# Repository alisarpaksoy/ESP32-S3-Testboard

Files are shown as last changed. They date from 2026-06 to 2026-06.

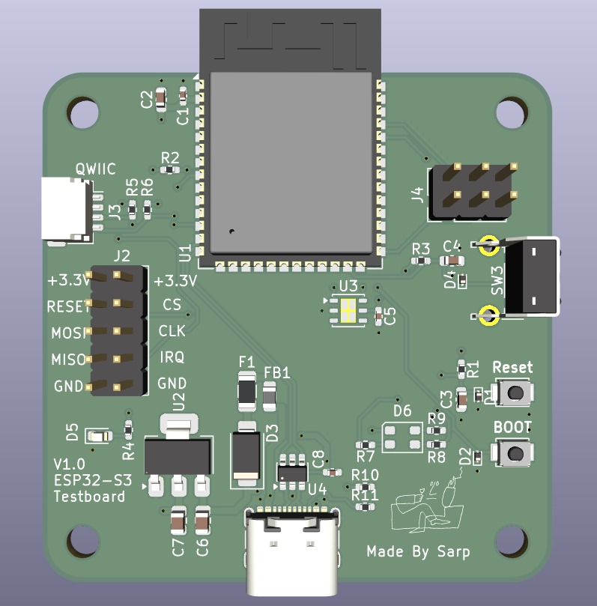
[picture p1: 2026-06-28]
Images/ESP32 S3 Layout.png

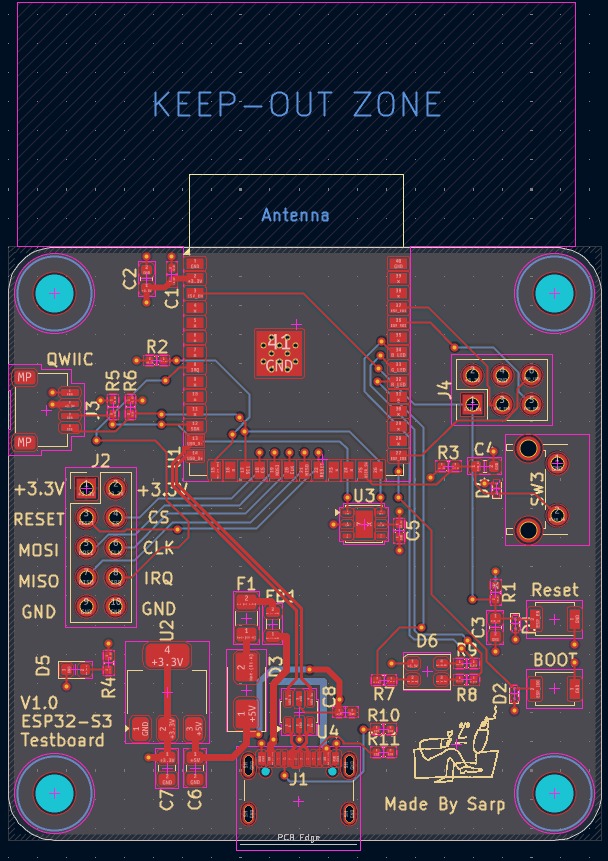
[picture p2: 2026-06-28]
Images/ESP32 S3 PCB.png

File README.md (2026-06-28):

# ESP32-S3 Testboard

## Overview

This project is a custom ESP32-S3 testboard designed in KiCad. The board was created as a compact development and testing platform for the ESP32-S3-WROOM module.

The board includes USB-C power and data connection, 3.3 V voltage regulation, boot and reset buttons, a user button, RGB LED, Qwiic I2C connector, GPIO headers, and an onboard Si7021-A20 temperature and humidity sensor.

The purpose of this project is to practice PCB design, ESP32-S3 hardware design, sensor integration, and GitHub-based engineering documentation.

## Main Features

* ESP32-S3-WROOM module
* USB-C connector for power and USB communication
* 5 V input from USB-C
* 3.3 V regulated power supply
* Boot and reset buttons
* User button
* RGB LED
* Si7021-A20 temperature and humidity sensor
* Qwiic I2C connector
* GPIO/SPI breakout headers
* ESD protection components
* Mounting holes
* ESP32-S3 antenna keepout area

## Hardware Description

### ESP32-S3 Module

The main microcontroller of the board is the ESP32-S3-WROOM module. It provides Wi-Fi, Bluetooth Low Energy, GPIO, USB, I2C, SPI, UART, PWM, ADC, and other peripheral interfaces.

The board exposes several ESP32-S3 pins through headers so the module can be used for testing and prototyping.

### Power Supply

The board is powered through the USB-C connector. The USB 5 V input is protected using a polyfuse and then regulated to 3.3 V using an LDO regulator.

The 3.3 V rail powers the ESP32-S3 module, Si7021 sensor, RGB LED, Qwiic connector, and supporting circuits.

### USB-C Interface

The USB-C connector provides power and USB data communication. The USB D+ and D− lines are connected to the ESP32-S3 USB pins for programming and serial communication.

### Boot and Reset Circuit

The board includes dedicated boot and reset buttons. The boot button is connected to GPIO0, and the reset button is connected to the ESP32-S3 enable/reset line.

These buttons allow the ESP32-S3 to be reset and placed into programming mode during firmware upload.

### Si7021 Temperature and Humidity Sensor

The board includes the Si7021-A20 digital temperature and humidity sensor. It communicates with the ESP32-S3 using the I2C bus.

This sensor can be used for:

* Temperature measurement
* Humidity measurement
* Environmental monitoring
* I2C communication testing

### Qwiic I2C Connector

A Qwiic connector is included for connecting external I2C modules. The connector provides:

* GND
* 3.3 V
* SDA
* SCL

Pull-up resistors are included on the I2C lines.

### RGB LED

The RGB LED is connected to ESP32-S3 GPIO pins through current-limiting resistors. It can be used for status indication, firmware testing, and GPIO output testing.

## Repository Structure

```text
ESP32-S3-Testboard/
│
├── README.md
├── .gitignore
│
├── kicad/
│   ├── ESP32-S3.kicad_pro
│   ├── ESP32-S3.kicad_sch
│   └── ESP32-S3.kicad_pcb
│
├── Images/
│   ├── schematic.png
│   ├── pcb_layout.png
│   └── pcb_3d_view.png
│
├── Documentation/
│   └── Datasheets/
│       ├── esp32-s3-wroom-1_wroom-1u_datasheet_en.pdf
│       └── Si7021-A20_datasheet.pdf
│
└── Manufacturing/
    ├── Gerbers/
    └── Drill/
```

## KiCad Project

The KiCad design files are located in the `kicad/` folder.

To open the project:

1. Install KiCad.
2. Open the `.kicad_pro` file.
3. Review the schematic and PCB layout.
4. Run ERC and DRC before modifying or manufacturing the board.

## Images

Project images are located in the `Images/` folder.

Included images:

* Schematic screenshot
* PCB layout screenshot
* 3D PCB render

## Manufacturing

Manufacturing files will be placed in the `Manufacturing/` folder.

Before ordering the PCB, the following checks should be completed:

* Electrical Rules Check
* Design Rules Check
* Gerber preview inspection
* Drill file verification
* USB-C footprint check
* ESP32-S3 footprint orientation check
* ESP32-S3 antenna keepout check
* Power trace width check
* I2C pull-up resistor verification

## Project Status

* [x] Schematic completed
* [x] PCB layout completed
* [x] ESP32-S3 module added
* [x] USB-C interface added
* [x] 3.3 V regulator added
* [x] Si7021 sensor added
* [x] Qwiic connector added
* [x] RGB LED added
* [ ] PCB manufactured
* [ ] Board assembled
* [ ] Power supply tested
* [ ] USB programming tested
* [ ] Si7021 sensor tested
* [ ] Example firmware added

## Author

Ali Sarp Aksoy
Mechatronics Engineering Student
Kraków, Poland

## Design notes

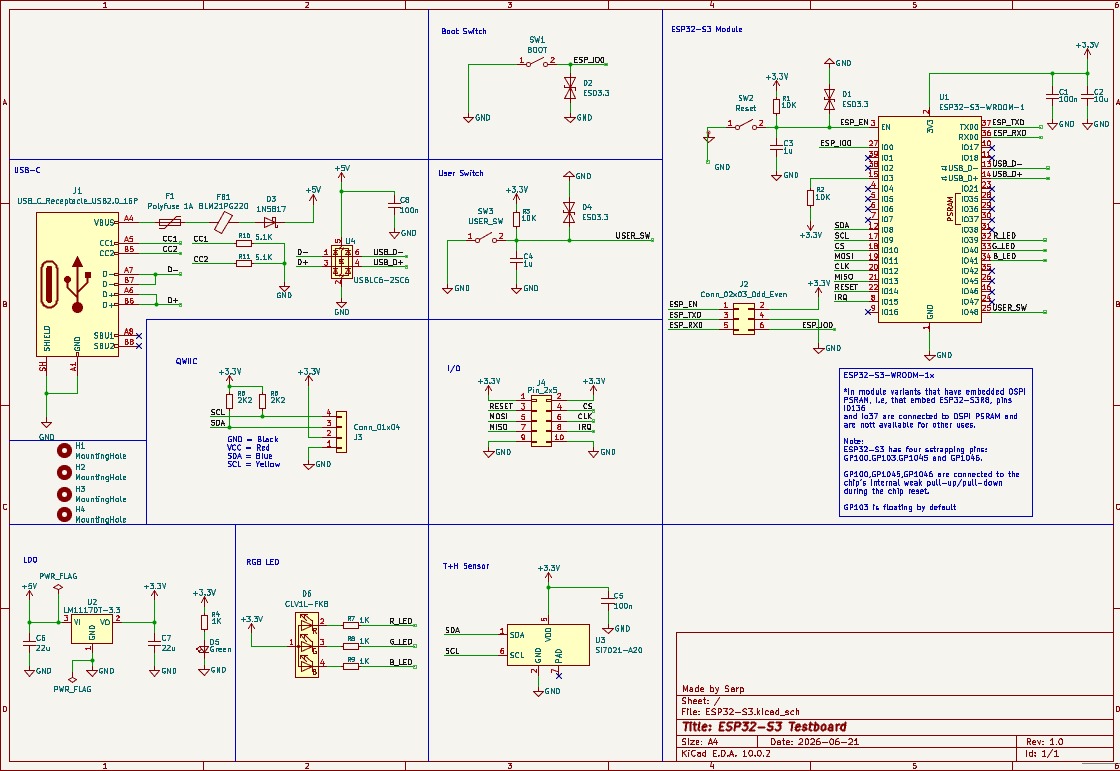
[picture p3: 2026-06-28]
Images/ESP32 S3 SCH.png

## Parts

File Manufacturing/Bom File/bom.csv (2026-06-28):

Designator | Footprint | Quantity | Value | LCSC Part #
C1, C5, C8 | 0402 | 3 | 100n
C2 | 0603 | 1 | 10u
C3, C4 | 0603 | 2 | 1u
C6, C7 | 0805 | 2 | 22u
D1, D2, D4 | D_SOD-923 | 3 | ESD3.3
D3 | D_SMA | 1 | 1N5817
D5 | 0603 | 1 | Green
D6 | LED_Cree-PLCC4_3.2x2.8mm_CCW | 1 | CLV1L-FKB
F1 | 1206 | 1 | Polyfuse 1A
FB1 | 0805 | 1 | BLM21PG220
J1 | USB_C_Receptacle_GCT_USB4105-xx-A_16P_TopMnt_Horizontal | 1 | USB_C_Receptacle_USB2.0_16P
J2 | PinHeader_2x05_P2.54mm_Vertical | 1 | Conn_02x03_Odd_Even
J3 | JST_SH_SM04B-SRSS-TB_1x04-1MP_P1.00mm_Horizontal | 1 | Conn_01x04
J4 | PinHeader_2x03_P2.54mm_Vertical | 1 | Pin_2x5
R1, R2, R3 | 0402 | 3 | 10K
R10, R11 | 0402 | 2 | 5.1K
R4, R7, R8, R9 | 0402 | 4 | 1K
R5, R6 | 0402 | 2 | 2K2
SW1 | SW_SPST_B3U-1000P | 1 | BOOT
SW2 | SW_SPST_B3U-1000P | 1 | Reset
SW3 | SW_Tactile_SPST_Angled_PTS645Vx31-2LFS | 1 | USER_SW
U1 | ESP32-S3-WROOM-1 | 1 | ESP32-S3-WROOM-1
U2 | SOT-223 | 1 | LM1117DT-3.3
U3 | DFN-6-1EP_3x3mm_P1mm_EP1.5x2.4mm | 1 | Si7021-A20
U4 | SOT-23-6 | 1 | USBLC6-2SC6

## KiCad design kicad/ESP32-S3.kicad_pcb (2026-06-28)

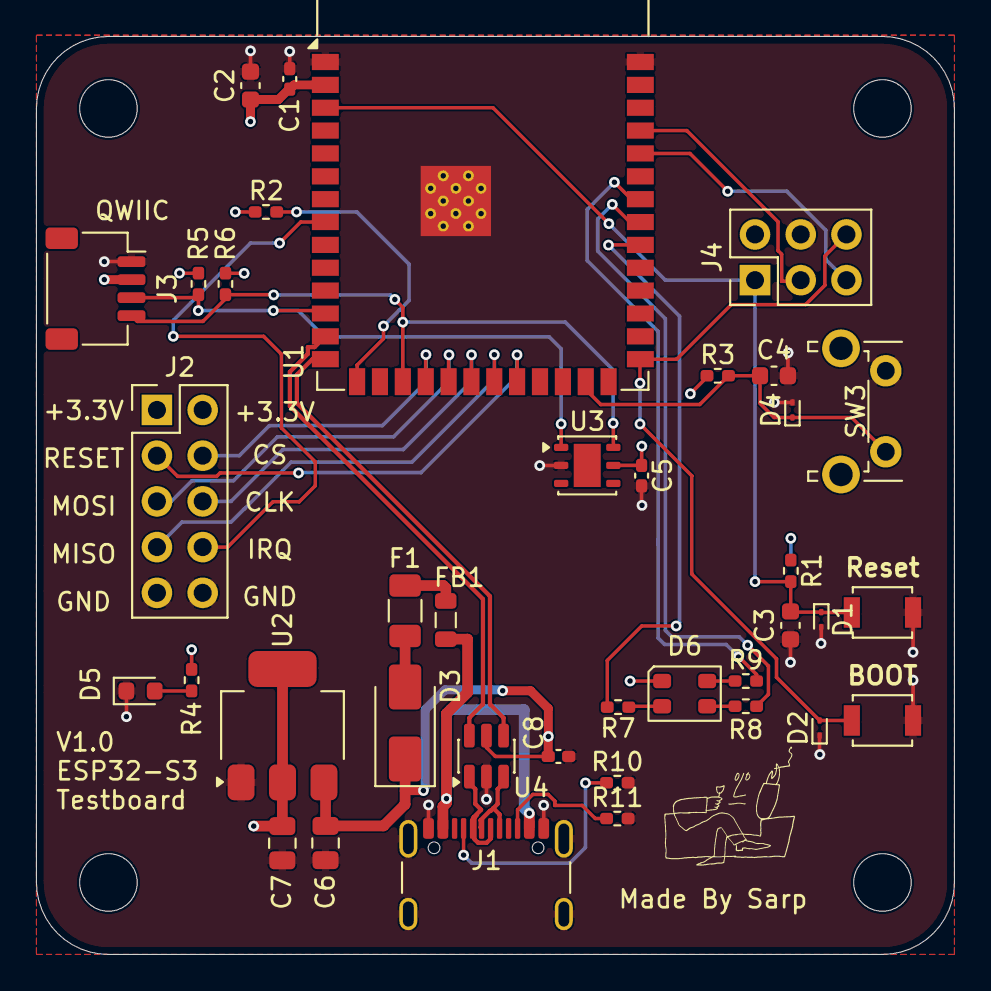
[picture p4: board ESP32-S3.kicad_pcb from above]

Board: 4 copper layers, 51.0 x 51.0 mm, 42 parts (0 on the bottom side), 33 nets.

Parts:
C1, C5, C8: 100n; C_0402_1005Metric_Pad0.74x0.62mm_HandSolder
C2: 10u; C_0603_1608Metric
C3, C4: 1u; C_0603_1608Metric
C6, C7: 22u; C_0805_2012Metric
D1, D2, D4: ESD3.3; D_SOD-923
D3: 1N5817; D_SMA
D5: Green; LED_0603_1608Metric
D6: CLV1L-FKB; LED_Cree-PLCC4_3.2x2.8mm_CCW
F1: Polyfuse 1A; Fuse_1206_3216Metric
FB1: BLM21PG220; L_0805_2012Metric
H1, H2, H3, H4: MountingHole; MountingHole_3.2mm_M3
J1: USB_C_Receptacle_USB2.0_16P; USB_C_Receptacle_GCT_USB4105-xx-A_16P_TopMnt_Horizontal
J2: Conn_02x03_Odd_Even; PinHeader_2x05_P2.54mm_Vertical
J3: Conn_01x04; JST_SH_SM04B-SRSS-TB_1x04-1MP_P1.00mm_Horizontal
J4: Pin_2x5; PinHeader_2x03_P2.54mm_Vertical
R1, R2, R3: 10K; R_0402_1005Metric_Pad0.72x0.64mm_HandSolder
R4, R7, R8, R9: 1K; R_0402_1005Metric_Pad0.72x0.64mm_HandSolder
R5, R6: 2K2; R_0402_1005Metric_Pad0.72x0.64mm_HandSolder
R10, R11: 5.1K; R_0402_1005Metric_Pad0.72x0.64mm_HandSolder
SW1: BOOT; SW_SPST_B3U-1000P
SW2: Reset; SW_SPST_B3U-1000P
SW3: USER_SW; SW_Tactile_SPST_Angled_PTS645Vx31-2LFS
U1: ESP32-S3-WROOM-1
U2: LM1117DT-3.3; SOT-223
U3: Si7021-A20; DFN-6-1EP_3x3mm_P1mm_EP1.5x2.4mm
U4: USBLC6-2SC6; SOT-23-6

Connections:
+3.3V: C1.1, C2.1, C5.1, C7.1, D6.1 (A), J2.1, J2.2, J3.2, J4.2, R1.1, R2.2, R3.1, R4.1, R5.1, R6.1, U1.2 (3V3), U2.2 (VO), U2.4, U3.5 (VDD)
+5V: C6.1, C8.1, D3.1 (K), U2.3 (VI), U4.5 (VBUS)
/B_LED: R9.2, U1.34 (IO41)
/CC1: J1.A5 (CC1), R10.1
/CC2: J1.B5 (CC2), R11.1
/CLK: J2.6, U1.20 (IO12)
/CS: J2.4, U1.18 (IO10)
/D+: J1.A6 (D+), J1.B6 (D+), U4.3 (I/O2)
/D-: J1.A7 (D-), J1.B7 (D-), U4.1 (I/O1)
/ESP_EN: C3.1, D1.1 (A1), J4.1, R1.2, SW2.2 (B), U1.3 (EN)
/ESP_IO0: D2.2 (A2), J4.6, SW1.2 (B), U1.27 (IO0)
/ESP_RXD: J4.5, U1.36 (RXD0)
/ESP_TXD: J4.3, U1.37 (TXD0)
/G_LED: R8.2, U1.33 (IO40)
/IRQ: J2.8, U1.8 (IO15)
/MISO: J2.7, U1.21 (IO13)
/MOSI: J2.5, U1.19 (IO11)
/RESET: J2.3, U1.22 (IO14)
/R_LED: R7.2, U1.32 (IO39)
/SCL: J3.4, R6.2, U1.17 (IO9), U3.6 (SCL)
/SDA: J3.3, R5.2, U1.12 (IO8), U3.1 (SDA)
/USB_D+: U1.14 (USB_D+), U4.4 (I/O2)
/USB_D-: U1.13 (USB_D-), U4.6 (I/O1)
/USER_SW: C4.1, D4.1 (A1), R3.2, SW3.2 (B), U1.25 (IO48)
GND: C1.2, C2.2, C3.2, C4.2, C5.2, C6.2, C7.2, C8.2, D1.2 (A2), D2.1 (A1), D4.2 (A2), D5.1 (K), J1.A1 (GND), J1.A12 (GND), J1.B1 (GND), J1.B12 (GND), J1.SH (SHIELD), J2.9, J2.10, J3.1, J4.4, R10.2, R11.2, SW1.1 (A), SW2.1 (A), SW3.1 (A), U1.1 (GND), U1.40 (GND), U1.41 (GND), U2.1 (GND), U3.2 (GND), U4.2 (GND)
unnamed: D3.2 (A), F1.1
unnamed: D5.2 (A), R4.2
unnamed: D6.4 (BK), R9.1
unnamed: D6.3 (GK), R8.1
unnamed: D6.2 (RK), R7.1
unnamed: FB1.1, J1.A4 (VBUS), J1.A9 (VBUS), J1.B4 (VBUS), J1.B9 (VBUS)
unnamed: F1.2, FB1.2
unnamed: R2.1, U1.15 (IO3)
